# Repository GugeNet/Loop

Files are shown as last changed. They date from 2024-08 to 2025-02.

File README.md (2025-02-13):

# Loop
4-track Eurorack Looper

A 4 hp wide 3U Eurorack module designed to be as simple as possible, but not simpler.

The user interface is limited but based on an idea of creating a linguistic model.

Not all of the ideas are implemented yet.

The commands consists of verbs: record, clear and loop. There are buttons for record and clear, a trigger input for loop.
In most situations there is also an implicit verb, such as mute.
The time aspect in the commands are either immidiate or suspended until loop. A short press means now, a long press means after the next loop command.
The objects are the four tracks.
The module will ask the user to select track by blinking the four track-buttons, or simetimes only the applicable tracks if appropriate.

Examples:

While playing click a green button and the track is muted and the button goues off.
Press the button for half a second instead of cust clicking and the button will blink green and start playing after the next loop.

Hold down record and notice all tracks blinking red as the module wants to know where to record. You can press one or more tracks and they will record after loop.

Another foundational idea is that every button has a function in any situation. There is no illegal action and the module is never unresponsive. The user is boss and presumably always has some intention.

So if the button for a blank track is pressed, it is presumed that record is the correct operation, while play is implicit for a track with sound.

The connections are stereo inputs and stereo outputs and a trigger input for loop.

There are six buttons. One bi-color illuminated pushbutton for each of the four tracks, one for clearing and one for record.

The basic operation of the module is to record to or play from four sound buffers and then on trigger loop to the beginning.

The module will always pass incoming sound through. Recording is additive, that is to say it doesn't remove existing sound from the track before recording.
Recording takes just the incoming sound.

Playing also adds sound to the incoming sound and when several tracks are playing they are all added equally to the incoming sound.

On reception of the loop trig the following scenarios are performed:

Playing -> Playing
Recording -> Playing
Muted -> Muted

The user can cue playing, recording or muting to happen on loop.

Record -> Track (long)
Track (long)
Clear -> Track (long)

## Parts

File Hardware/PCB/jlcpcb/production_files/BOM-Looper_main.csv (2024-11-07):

Comment | Designator | Footprint | LCSC | Quantity
MMBT3904 | Q1 | SOT-23 | C20526 | 1
1K | R27 | R_0603_1608Metric | C21190 | 1
130 | R1,R2,R3,R4 | R_0603_1608Metric | C22796 | 4
100K | R11,R29 | R_0603_1608Metric | C25803 | 2
10K | R26 | R_0603_1608Metric | C25804 | 1

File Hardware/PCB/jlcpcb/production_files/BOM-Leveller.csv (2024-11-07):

Comment | Designator | Footprint | LCSC | Quantity
FerriteBead | FB1,FB2 | R_0603_1608Metric | C1002 | 2
TL074 | U1,U2 | SOIC127P600X175-14N | C12594 | 2
100nF | C1,C11,C12,C5 | C_0603_1608Metric | C14663 | 4
47pF | C10,C14,C2,C7,C8,C9 | C_0603_1608Metric | C1671 | 6
1K | R12,R16,R22,R8 | R_0603_1608Metric | C21190 | 4
100K | R10,R13,R15,R17,R18,R19,R20,R23,R24,R25,R6,R9 | R_0603_1608Metric | C25803 | 12
10K | R14,R21,R5,R7 | R_0603_1608Metric | C25804 | 4
560pF | C13,C3 | C_0603_1608Metric | C458906 | 2
1N5819 | D1,D4 | D_SOD-123 | C5451628 | 2
10uF | C4,C6 | CP_Elec_4x5.4 | C88654 | 2

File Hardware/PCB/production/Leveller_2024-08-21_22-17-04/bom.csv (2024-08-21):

Designator | Footprint | Quantity | Value | LCSC Part #
C1, C11, C12, C5 | 0603 | 4 | 100nF | C14663
C10, C7, C8, C9 | 0603 | 4 | 47pF | C1671
C2, C3 | 0603 | 2 | 560pF | C458906
C4, C6 | CP_Elec_4x5.4 | 2 | 10uF | C88654
D1, D4 | D_SOD-123 | 2 | 1N5819 | C5451628
FB1, FB2 | 0603 | 2 | FerriteBead | C1002
R10, R13, R15, R17, R18, R19, R20, R6 | 0603 | 8 | 100K | C25803
R11, R14, R21, R7 | 0603 | 4 | 10K | C25804
R12, R16, R22, R8 | 0603 | 4 | 1K | C21190
R5, R9 | 0603 | 2 | 2M | C22976
U1, U2 | SOIC127P600X175-14N | 2 | TL074 | C12594

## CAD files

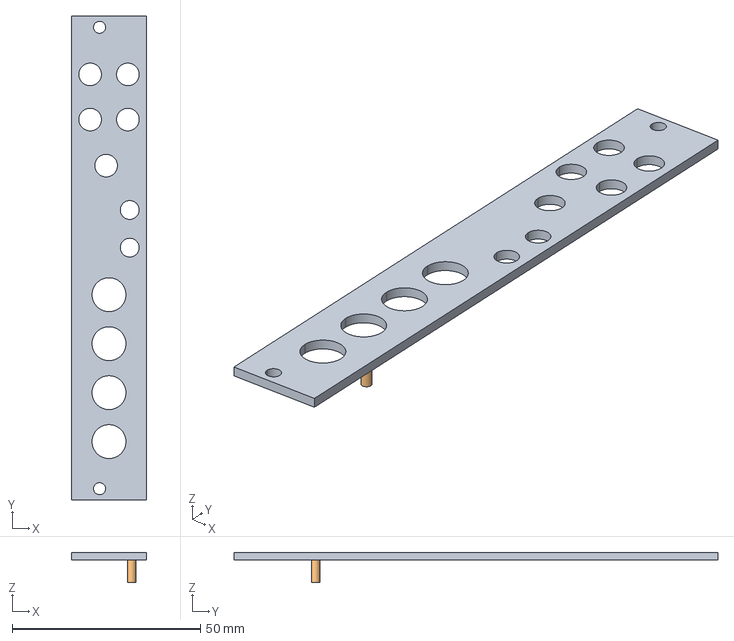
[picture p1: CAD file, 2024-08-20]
Hardware/PCB/Loop.stp
20.0 x 128.5 x 8.00 mm

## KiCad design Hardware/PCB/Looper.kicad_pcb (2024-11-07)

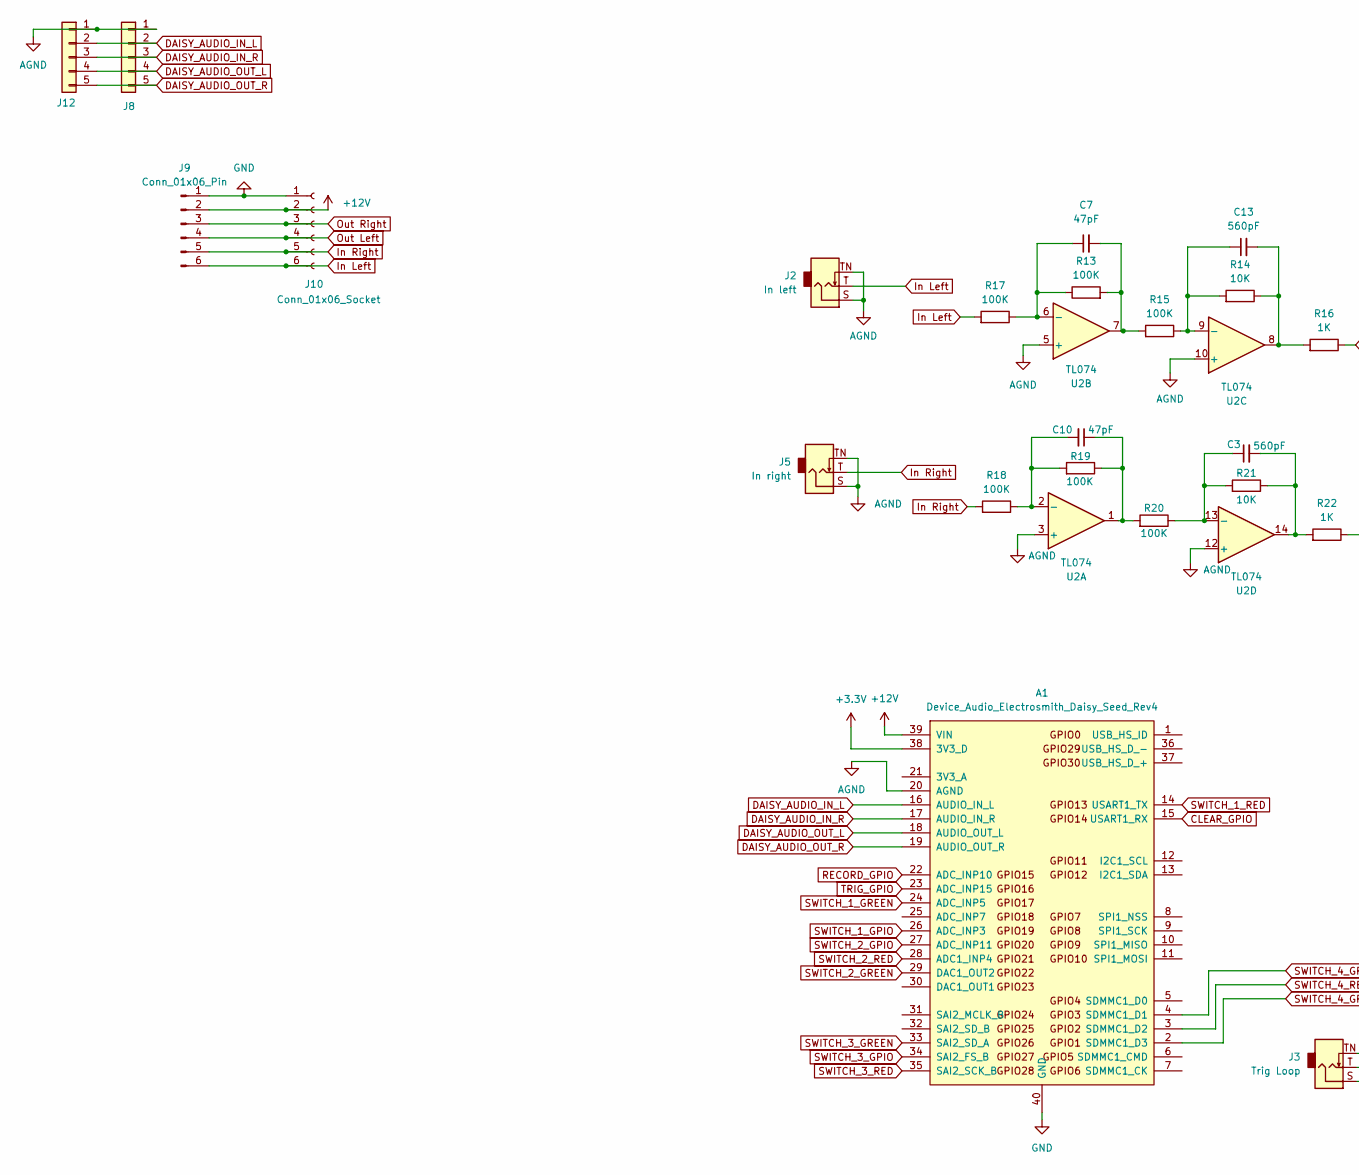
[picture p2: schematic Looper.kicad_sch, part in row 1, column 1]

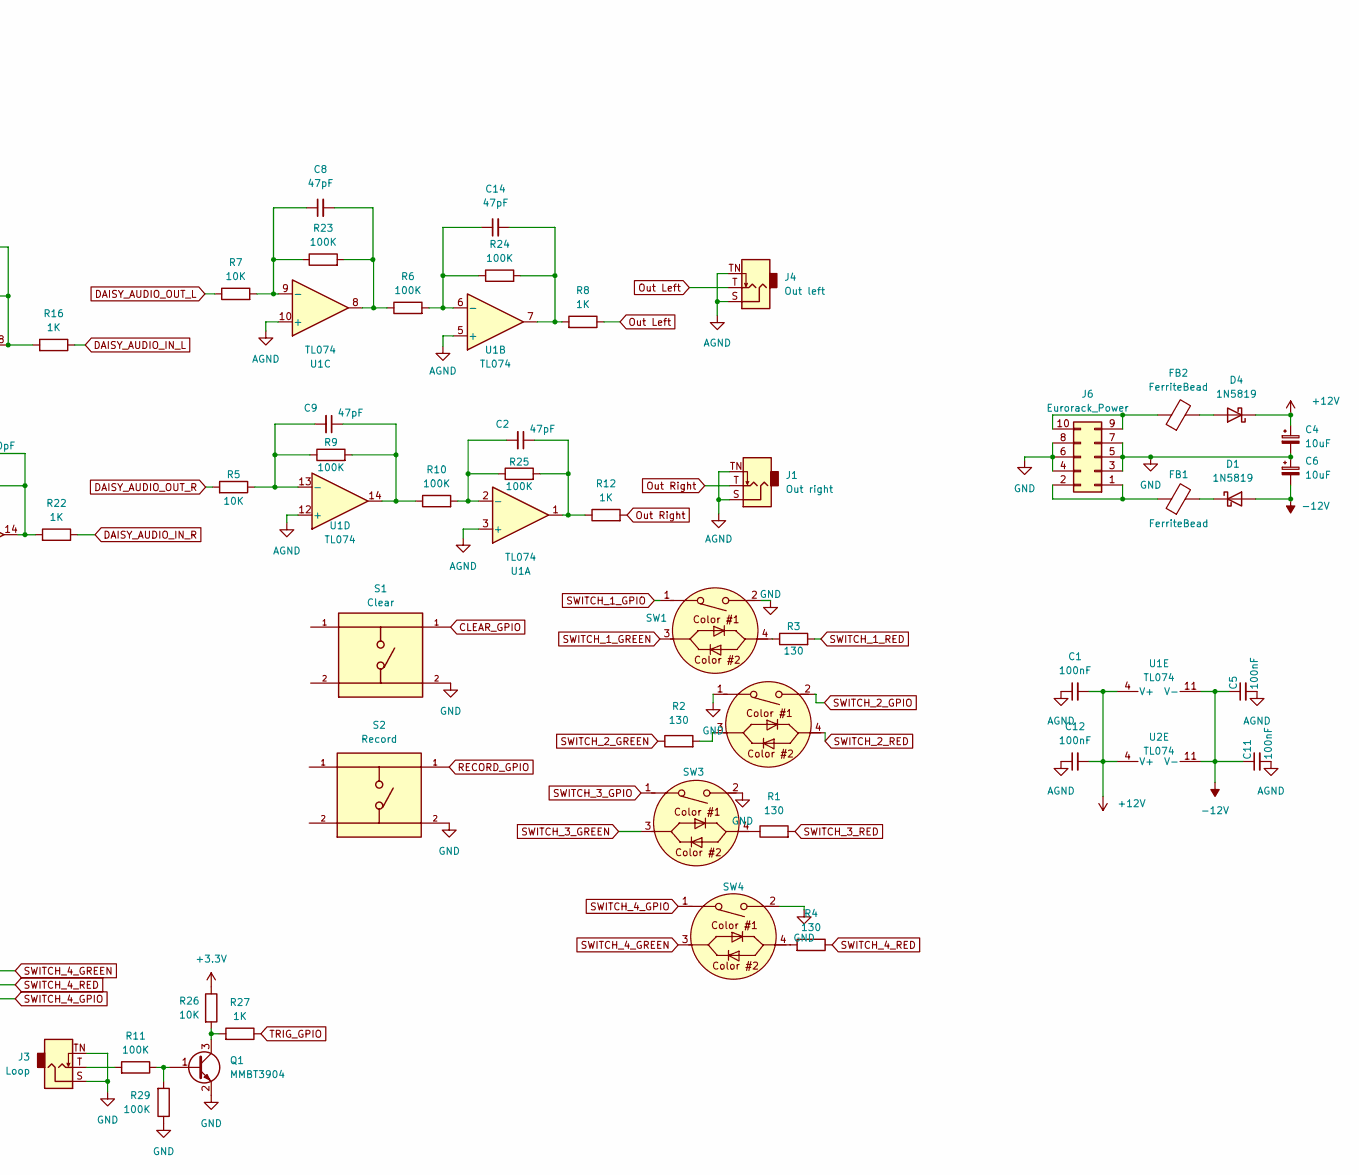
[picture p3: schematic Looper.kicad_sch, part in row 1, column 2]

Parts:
A1: Device_Audio_Electrosmith_Daisy_Seed_Rev4; Device_Audio_Electrosmith_Daisy_Seed
C1, C5, C11, C12: 100nF; C_0603_1608Metric; LCSC C14663
C2, C7, C8, C9, C10, C14: 47pF; C_0603_1608Metric; LCSC C1671
C3, C13: 560pF; C_0603_1608Metric; LCSC C458906
C4, C6: 10uF; CP_Elec_4x5.4; LCSC C88654
D1, D4: 1N5819; D_SOD-123; LCSC C5451628
FB1, FB2: FerriteBead; R_0603_1608Metric; LCSC C1002
J1: Out right; Jack_3.5mm_QingPu_WQP-PJ398SM_Vertical
J2: In left; Jack_3.5mm_QingPu_WQP-PJ398SM_Vertical
J3: Trig Loop; Jack_3.5mm_QingPu_WQP-PJ398SM_Vertical
J4: Out left; Jack_3.5mm_QingPu_WQP-PJ398SM_Vertical
J5: In right; Jack_3.5mm_QingPu_WQP-PJ398SM_Vertical
J6: Eurorack_Power; PinHeader_2x05_P2.54mm_Vertical
J8, J12: Conn_01x05; PinHeader_1x05_P2.54mm_Vertical
J9: Conn_01x06_Pin; PinHeader_1x06_P2.54mm_Vertical
J10: Conn_01x06_Socket; PinHeader_1x06_P2.54mm_Vertical
Q1: MMBT3904; SOT-23; LCSC C20526
R1, R2, R3, R4: 130; R_0603_1608Metric; LCSC C22796
R5, R7, R14, R21, R26: 10K; R_0603_1608Metric; LCSC C25804
R6, R9, R10, R11, R13, R15, R17, R18, R19, R20, R23, R24, R25, R29: 100K; R_0603_1608Metric; LCSC C25803
R8, R12, R16, R22, R27: 1K; R_0603_1608Metric; LCSC C21190
S1: Clear; SW_TS02-66-140-BK-160-LCR-D; PARTREV 1.0
S2: Record; SW_TS02-66-140-BK-160-LCR-D; PARTREV 1.0
SW1, SW2, SW3, SW4: D6RLRDGNF1LFS
U1, U2: TL074; SOIC127P600X175-14N; LCSC C12594

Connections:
+3.3V: A1.38 (3V3_D), R26.1
+12V: A1.39 (VIN), C1.2, C4.1, C12.2, D4.1 (K), J9.2, J10.2, U1.4 (V+), U2.4 (V+)
-12V: C5.1, C6.2, C11.1, D1.2 (A), U1.11 (V-), U2.11 (V-)
AGND: A1.20 (AGND), C1.1, C5.2, C11.2, C12.1, J1.S, J1.TN, J2.S, J2.TN, J4.S, J4.TN, J5.S, J5.TN, J8.1, J12.1, U1.3 (+), U1.5 (+), U1.10 (+), U1.12 (+), U2.3 (+), U2.5 (+), U2.10 (+), U2.12 (+)
CLEAR_GPIO: A1.15 (USART1_RX), S1.1
DAISY_AUDIO_IN_L: A1.16 (AUDIO_IN_L), J8.2, J12.2, R16.1
DAISY_AUDIO_IN_R: A1.17 (AUDIO_IN_R), J8.3, J12.3, R22.1
DAISY_AUDIO_OUT_L: A1.18 (AUDIO_OUT_L), J8.4, J12.4, R7.1
DAISY_AUDIO_OUT_R: A1.19 (AUDIO_OUT_R), J8.5, J12.5, R5.2
GND: A1.40 (GND), C4.2, C6.1, J3.S, J3.TN, J6.3, J6.4, J6.5, J6.6, J6.7, J6.8, J9.1, J10.1, Q1.2 (E), R29.1, S1.2, S2.2, SW1.2, SW2.1, SW3.2, SW4.2
In Left: J2.T, J9.6, J10.6, R17.2
In Right: J5.T, J9.5, J10.5, R18.2
unnamed: C2.1, R12.1, R25.2, U1.1
unnamed: C3.2, R21.1, R22.2, U2.14
unnamed: C7.2, R13.2, R15.2, U2.7
unnamed: C8.2, R6.1, R23.2, U1.8
unnamed: C9.1, R9.2, R10.1, U1.14
unnamed: C10.1, R19.1, R20.2, U2.1
unnamed: C13.2, R14.1, R16.2, U2.8
unnamed: C14.2, R8.2, R24.2, U1.7
unnamed: D1.1 (K), FB1.2
unnamed: D4.2 (A), FB2.2
unnamed: J3.T, R11.2
unnamed: FB1.1, J6.1, J6.2
unnamed: FB2.1, J6.9, J6.10
unnamed: Q1.1 (B), R11.1, R29.2
unnamed: Q1.3 (C), R26.2, R27.2
unnamed: R1.1, SW3.4
unnamed: R2.2, SW2.3
unnamed: R3.1, SW1.4
unnamed: R4.2, SW4.4
unnamed: C2.2, R10.2, R25.1, U1.2 (-)
unnamed: C14.1, R6.2, R24.1, U1.6 (-)
unnamed: C8.1, R7.2, R23.1, U1.9 (-)
unnamed: C9.2, R5.1, R9.1, U1.13 (-)
unnamed: C10.2, R18.1, R19.2, U2.2 (-)
unnamed: C7.1, R13.1, R17.1, U2.6 (-)
unnamed: C13.1, R14.2, R15.1, U2.9 (-)
unnamed: C3.1, R20.1, R21.2, U2.13 (-)
Out Left: J4.T, J9.4, J10.4, R8.1
Out Right: J1.T, J9.3, J10.3, R12.2
RECORD_GPIO: A1.22 (ADC_INP10), S2.1
SWITCH_1_GPIO: A1.26 (ADC_INP3), SW1.1
SWITCH_1_GREEN: A1.24 (ADC_INP5), SW1.3
SWITCH_1_RED: A1.14 (USART1_TX), R3.2
SWITCH_2_GPIO: A1.27 (ADC_INP11), SW2.2
SWITCH_2_GREEN: A1.29 (DAC1_OUT2), R2.1
SWITCH_2_RED: A1.28 (ADC1_INP4), SW2.4
SWITCH_3_GPIO: A1.34 (SAI2_FS_B), SW3.1
SWITCH_3_GREEN: A1.33 (SAI2_SD_A), SW3.3
SWITCH_3_RED: A1.35 (SAI2_SCK_B), R1.2
SWITCH_4_GPIO: A1.2 (SDMMC1_D3), SW4.1
SWITCH_4_GREEN: A1.4 (SDMMC1_D1), SW4.3
SWITCH_4_RED: A1.3 (SDMMC1_D2), R4.1
TRIG_GPIO: A1.23 (ADC_INP15), R27.1

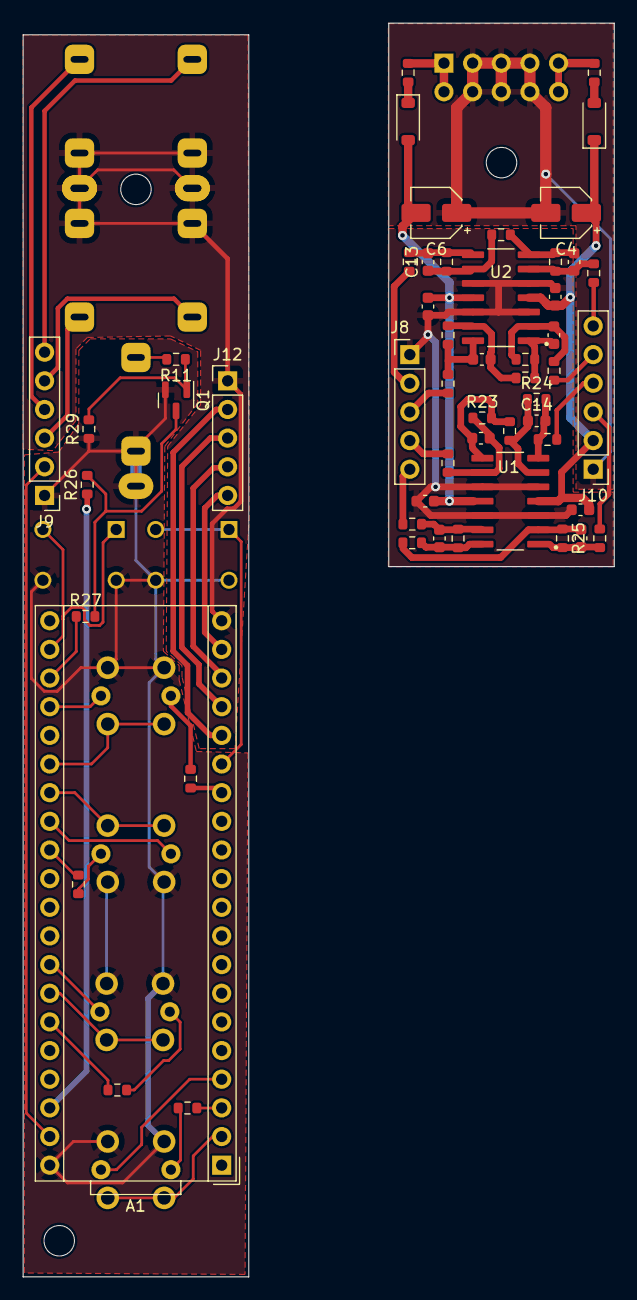
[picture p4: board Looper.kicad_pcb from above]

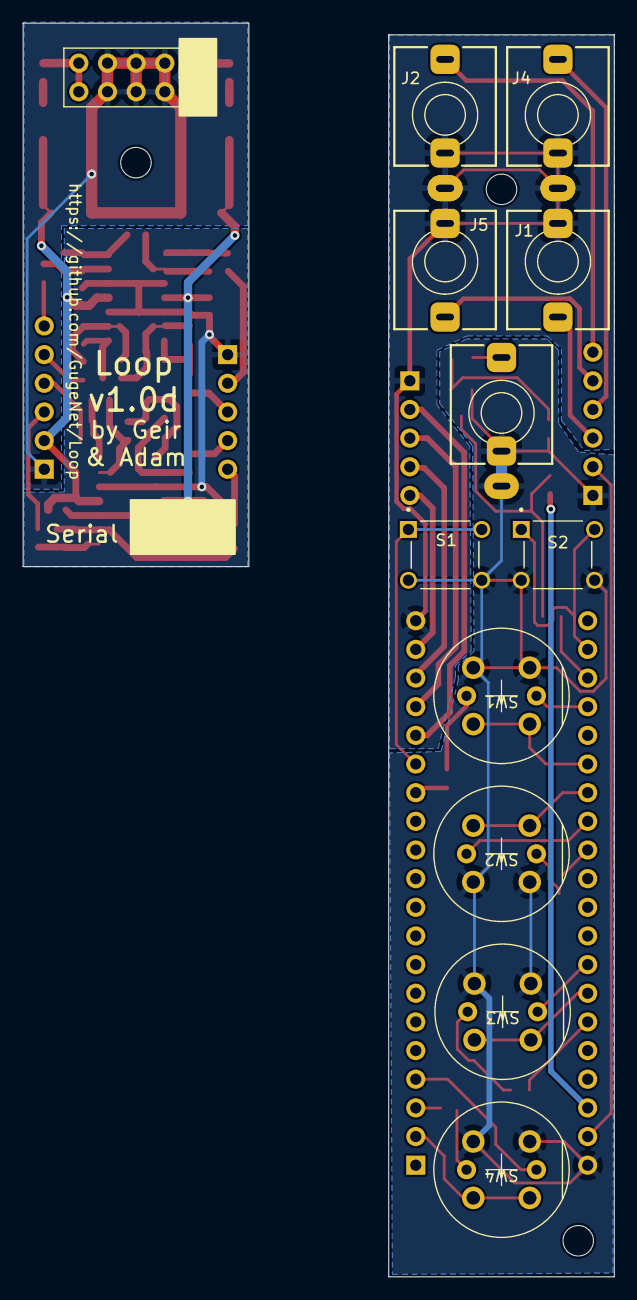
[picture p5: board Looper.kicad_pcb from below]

Board: 2 copper layers, 52.4 x 111.1 mm, 69 parts (12 on the bottom side), 55 nets.

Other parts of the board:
MOUNT1, MOUNT1#2, MOUNT1#3: MountingHole_2.7mm_M2.5

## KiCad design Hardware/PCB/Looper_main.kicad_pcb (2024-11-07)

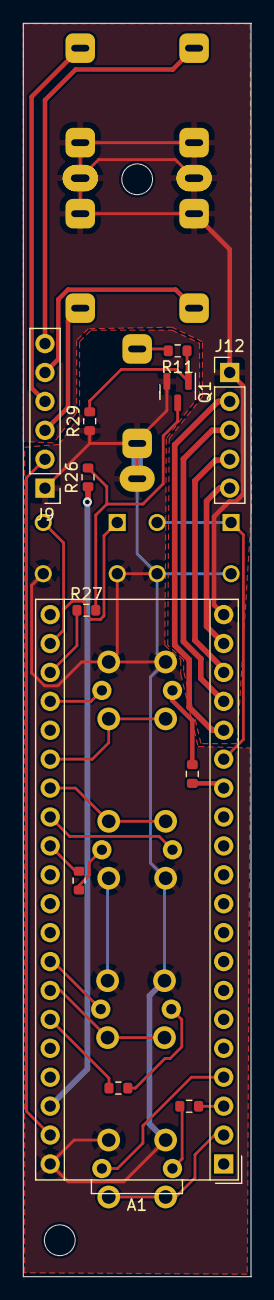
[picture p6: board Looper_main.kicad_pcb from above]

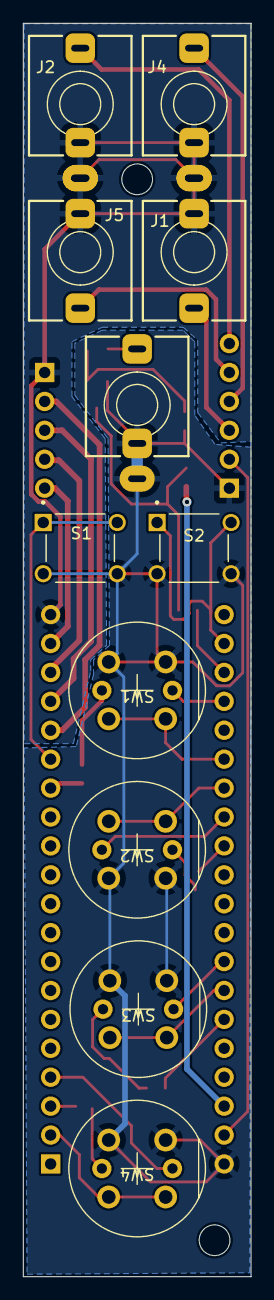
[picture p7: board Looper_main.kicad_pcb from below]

Board: 2 copper layers, 20.0 x 110.1 mm, 25 parts (11 on the bottom side), 8 nets.

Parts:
A1: Device_Audio_Electrosmith_Daisy_Seed_Rev4; Device_Audio_Electrosmith_Daisy_Seed
J1: Out right; Jack_3.5mm_QingPu_WQP-PJ398SM_Vertical
J2: In left; Jack_3.5mm_QingPu_WQP-PJ398SM_Vertical
J3: Trig Loop; Jack_3.5mm_QingPu_WQP-PJ398SM_Vertical
J4: Out left; Jack_3.5mm_QingPu_WQP-PJ398SM_Vertical
J5: In right; Jack_3.5mm_QingPu_WQP-PJ398SM_Vertical
J9: Conn_01x06_Pin; PinHeader_1x06_P2.54mm_Vertical
J12: Conn_01x05; PinHeader_1x05_P2.54mm_Vertical
MOUNT1, MOUNT1#2: MountingHole_2.7mm_M2.5
Q1: MMBT3904; SOT-23
R1, R2, R3, R4: 130; R_0603_1608Metric
R11, R29: 100K; R_0603_1608Metric
R26: 10K; R_0603_1608Metric
R27: 1K; R_0603_1608Metric
S1: Clear; SW_TS02-66-140-BK-160-LCR-D
S2: Record; SW_TS02-66-140-BK-160-LCR-D
SW1, SW2, SW3, SW4: D6RLRDGNF1LFS

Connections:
+3.3V: A1.38 (3V3_D), R26.1
+12V: A1.39 (VIN), J9.2
GND: A1.40 (GND), J3.S, J3.TN, J9.1, Q1.2 (E), R29.1, S1.2, S2.2, SW1.2, SW2.1, SW3.2, SW4.2
In Left: J2.T, J9.6
unnamed: R3.1, SW1.4
unnamed: R4.2, SW4.4
Out Left: J4.T, J9.4
Out Right: J1.T, J9.3

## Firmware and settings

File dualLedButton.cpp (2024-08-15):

#include "daisy_seed.h"
#include "daisysp.h"
#include "dualLedButton.h"

using namespace daisy;

void DualLedButton::Init(Pin pin, float rate, Pin greenLedPin, Pin redLedPin)
{
    button.Init(pin, rate, Switch::TYPE_MOMENTARY, Switch::POLARITY_INVERTED, Switch::PULL_UP);
    redGpio.Init(redLedPin, GPIO::Mode::OUTPUT);
    greenGpio.Init(greenLedPin, GPIO::Mode::OUTPUT);
}

void DualLedButton::Debounce()
{
    button.Debounce();
}

bool DualLedButton::Pressed()
{
    return button.Pressed();
}

bool DualLedButton::RisingEdge()
{
    return button.RisingEdge();
}

void DualLedButton::Off()
{
    redGpio.Write(false);
    greenGpio.Write(false);
}

void DualLedButton::Red()
{
    redGpio.Write(true);
    greenGpio.Write(false);
}

void DualLedButton::Green()
{
    redGpio.Write(false);
    greenGpio.Write(true);
}

void DualLedButton::Color(int color)
{
    redGpio.Write(color == 1);
    greenGpio.Write(color == 2);
}

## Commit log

2023-11-21 Initial test with button and leds
2023-11-24 Track buttons work
2023-11-25 Recording button working
2024-08-15 Track Buttons working
2024-08-20 Hardware added
    [Leveller-B_Cu.gbl, Leveller-B_Mask.gbs, Leveller-B_Paste.gbp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]
2024-08-21 Version 1.0 of hardware ordered
    [Leveller.kicad_pcb, Looper.kicad_pcb, Looper_main.kicad_pcb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]
2024-08-28 Leveller 1.0b
    [Leveller-B_Cu.gbl, Leveller-B_Mask.gbs, Leveller-B_Paste.gbp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]
2024-08-29 Fixed power diode polarity
    [Looper.kicad_pcb, Looper.kicad_sch]
2024-09-03 new intracard connections
    [Looper.kicad_pcb, Looper.kicad_sch]
2024-09-08 more labels
    [Looper.kicad_pcb, Looper.kicad_sch]
2024-09-08 Endret hele leveller
    [Looper.kicad_pcb, Looper.kicad_sch]
2024-09-19 HW 1.0c
    [Leveller.kicad_pcb, Looper.kicad_pcb, Looper.kicad_sch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]
2024-11-07 Version 1.0d hardware
    [BOM-Leveller.csv, BOM-Looper_main.csv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]
2024-11-11 record and clear buttons
2024-11-28 HW Version D
    [bom.csv, designators.csv, positions.csv]
